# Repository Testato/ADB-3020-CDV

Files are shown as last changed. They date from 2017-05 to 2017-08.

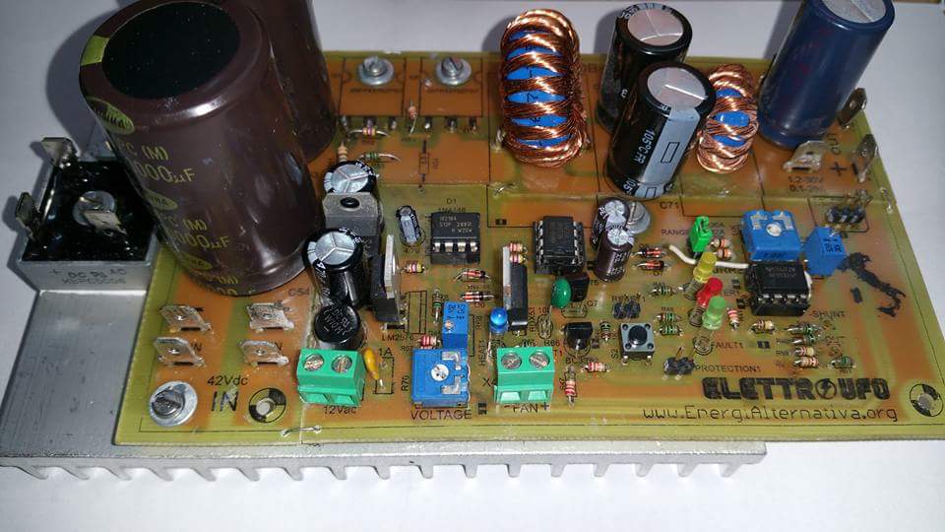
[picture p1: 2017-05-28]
adb_2030_Original/PCB_top_side.jpg

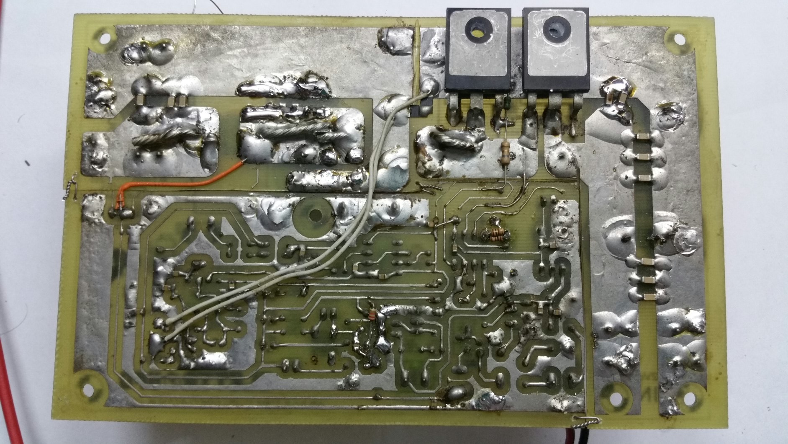
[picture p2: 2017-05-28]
adb_2030_Original/PCB_bottom_side.jpg

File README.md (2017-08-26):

# ADB-3020-CDV



The ADB-3020 is an excellent switching power supply designed by an Italian team and licensed under Creative Commons (the original project and credits are in the adb_2030_Original subfolder).

The CDV (Community Digital Version) fork is intended to start with version 2.1 (last published on the fork date) and then extend it with digital functions via MCU.
The project started with the creation of Eagle .sch because the original authors have decided not to release the productions files. 
Now Eagle file is deprecated, the project is ported on KiCAD.

The CDV version is released under the same license as the original project:
- https://creativecommons.org/licenses/by-nc-sa/4.0/

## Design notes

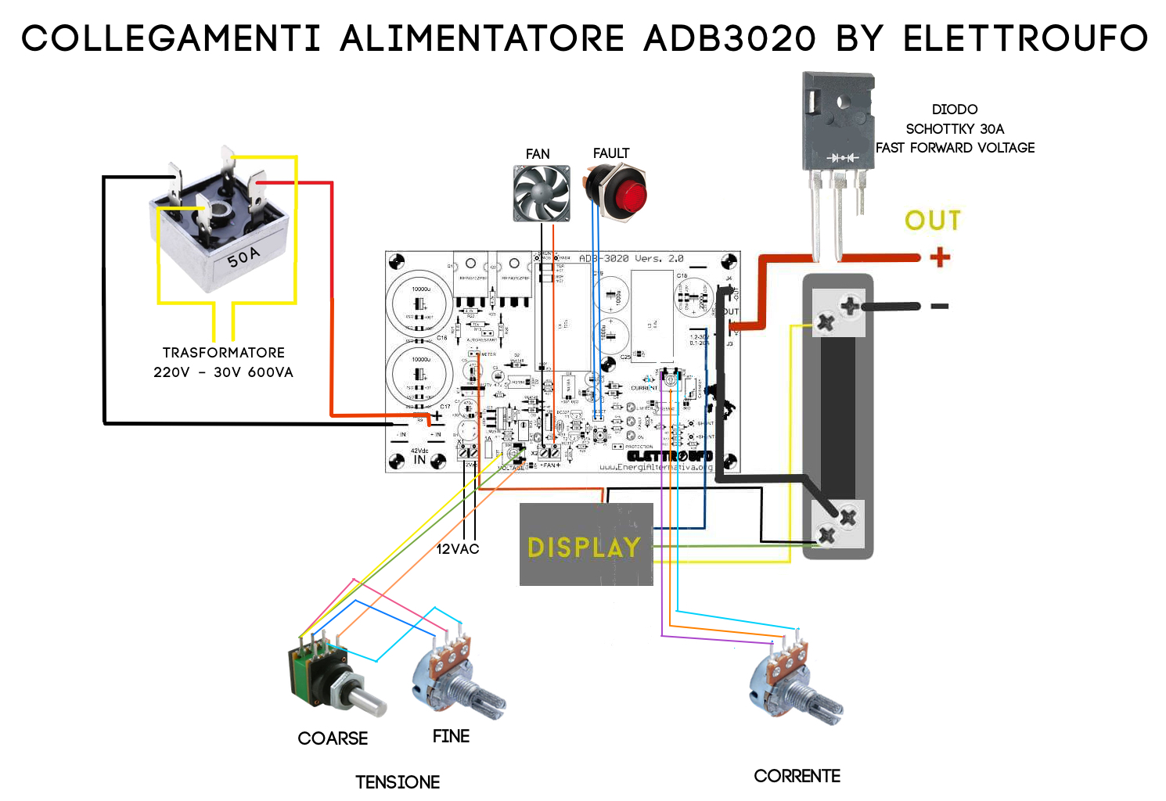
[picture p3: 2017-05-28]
adb_2030_Original/External_connections.jpg

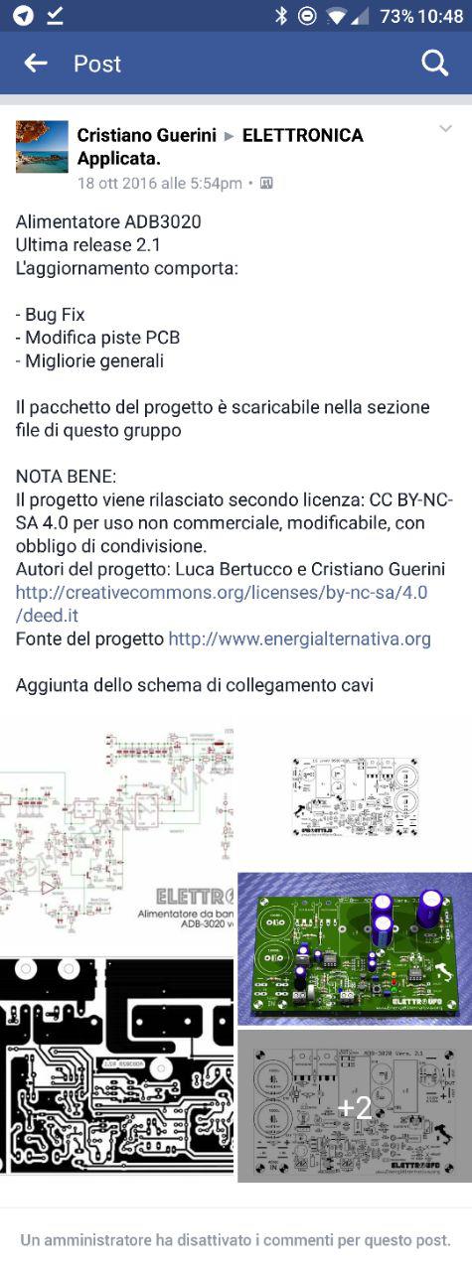
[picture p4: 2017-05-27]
adb_2030_Original/ORIGINAL_LICENCE.jpg

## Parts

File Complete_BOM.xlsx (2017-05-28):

Part | Value | Package | Library | Position (inch) | Orientation | Codice TME | Indirizzo | QTY
B1 | Ponte diodi | RB1A | rectifier | (1.475 0.7625) | R270 | VISHAY 2W01G-E4/51 | http://www.tme.eu/it/details/2w01g-e4_51/ponti-a-diodi-monofase-rotondi/vishay/ | 1
C | 100n | C0805 | rcl | (4.7375 1.2375) | MR270 | SAMSUNG CL21B104KBCNNNC | http://www.tme.eu/it/details/cl21b104kbcnnnc/condensatori-mlcc-smd-0805/samsung/ | 8
C | 100n (100V) | C1206 | rcl | (0.6 1.35) | MR0 | YAGEO CC1206JRX7R9BB104 | http://www.tme.eu/it/details/cc1206kkx7r0104/condensatori-mlcc-smd-1206/yageo/cc1206kkx7r0bb104/ | 5
C | 1000u | E7,5-16 | rcl | (4 3.1625) | R90 | PANASONIC EEUFR1H102 | http://www.tme.eu/it/details/eeufr1h102/condensatori-elettrol-tht-bassa-imped/panasonic/ | 2
C | 10000u | EB30D | rcl | (0.6 3) | R180 | SAMWHA HE1H109M30050HA | http://www.tme.eu/it/details/he1h109m30050ha/condensatori-elettrolitici-snapin-105c/samwha/ | 2
C1 | 470u | E5-8,5 | rcl | (1.475 1.1375) | R180 | SAMXON GT 470U/25V | http://www.tme.eu/it/details/gt470_25/condensatori-elettrol-tht-bassa-imped/samxon/gt-470u25v/ | 2
C11 | 10n | C0805 | rcl | (2.58598954 0.13147047) | MR270 | SAMSUNG CL21B103JBANNNC | http://www.tme.eu/it/details/cl21b103jbannnc/condensatori-mlcc-smd-0805/samsung/ | 3
C15 | 470n | C0805 | rcl | (3.5 0.675) | MR270 | SAMSUNG CL21B474KOFNNNG | http://www.tme.eu/it/details/cl21b474kofnnng/condensatori-mlcc-smd-0805/samsung/ | 1
C18 | 2200u | E7,5-18 | rcl | (5.475 3.1125) | R90 | PANASONIC EEUFC1H222 | http://www.tme.eu/it/details/eeufc1h222/condensatori-elettrol-tht-bassa-imped/panasonic/ | 1
C20 | 10n (100V) | C1206 | rcl | (0.6 2.3375) | MR0 | CL31B103KBCNNNC | http://www.tme.eu/it/details/cl31b103kccnnnc/condensatori-mlcc-smd-1206/samsung/ | 4
C36 | 100u | E2,5-7 | rcl | (3.675 1.6625) | R270 | SR PASSIVES CE-100/35PHT | http://www.tme.eu/it/details/ce-100_35pht/condensatori-elettrolitici-tht-105c/sr-passives/ | 2
C9 | 4.7u | E2,5-6 | rcl | (2 1.7125) | R270 | NICHICON UPW1E4R7MDD | http://www.tme.eu/it/details/upw1e4r7mdd/condensatori-elettrol-tht-bassa-imped/nichicon/ | 1
D1 | 1N4148 | DO35-10 | diode | (2.625 1.2625) | R180 | DIOTEC SEMICONDUCTOR 1N4148 | http://www.tme.eu/it/details/1n4148-dio/diodi-universali-tht/diotec-semiconductor/1n4148/ | 6
D6 | 7812TV | TO220V | linear | (1.55 1.525) | R0 | ST MICROELECTRONICS L7812ABV | http://www.tme.eu/it/details/l7812abv/stabilizzatori-di-tens-non-regolabili/st-microelectronics/ | 1
F1 | PTCPTH | PTC | SparkFun-PowerIC | (1.83053223 0.41229921 | ) R90 | ECE BX075 | http://www.tme.eu/it/details/bx075/fusibili-polimerici-tht/ece/ | 1
IC2 | NE5532 | DIL08 | linear | (5.0125 1.1375) | R0 | TEXAS INSTRUMENTS NE5532P | http://www.tme.eu/it/details/ne5532p/amplificatori-operazionali-tht/texas-instruments/ | 1
IC3 | LM2576 | TO220-51 | linear | (2.1375 0.9625) | R270 | TEXAS INSTRUMENTS LM2576HVT-ADJ/LF03 | http://www.tme.eu/it/details/lm2576hvtadj_lf/regolatori-di-tensione-circuiti-dc-dc/texas-instruments/lm2576hvt-adjlf03/ | 1
IC4 | NE555 | DIL-08 | st-microelectronics | (3.25 1.525) | R90 | TEXAS INSTRUMENTS NE555P | http://www.tme.eu/it/details/ne555p/circuiti-watchdog-e-reset/texas-instruments/ | 1
IC5 | IR2184D | DIL08 | irs | (2.375 1.6125) | R0 | INFINEON (IRF) IR2184PBF | http://www.tme.eu/it/details/ir2184pbf/driver-mosfetigbt/infineon-irf/ | 1
Jumper |  | JP1 | jumper | (1.575 2.1125) | R90 | NINIGI JUMPER-H/B | http://www.tme.eu/it/details/jumper-h_b/prese-e-spine-tipo-c-gird/ninigi/ | 3
L3 | 6.8u | TJ7-U1 | resistor | (4.7375 2.775) | R0 | FERYSTER DTMSS-16/0.0068/20-V | http://www.tme.eu/it/details/dtmss-16_0.0068_20/induttori-ad-anello/feryster/dtmss-160006820-v/ | 1
L4 | 100u | TJ8-U1 | resistor | (3.15 2.7625) | R0 | FERYSTER DTMSS-47/0.10/30-V | http://www.tme.eu/it/details/dtmss-47_0.10_30-v/induttori-ad-anello/feryster/ | 1
Lastra rame | 100x160 |  |  |  |  | LAM100X160L1.5 | http://www.tme.eu/it/details/lam100x160l1.5/laminati-unilaterali/ | 1
led FAULT | Red | LED3MM | led | (4.35 0.9125) | R180 | KINGBRIGHT ELECTRONIC L-934SRD-F | http://www.tme.eu/it/details/l-934srd-f/diodi-led-tht-3mm/kingbright-electronic/ | 1
led HEAT | Green | LED3MM | led | (2.7 0.625) | R180 | KINGBRIGHT ELECTRONIC L-934GD | http://www.tme.eu/it/details/l-934gd/diodi-led-tht-3mm/kingbright-electronic/ | 1
led LIMITER | Yellow | LED3MM | led | (4.35 1.1625) | R180 | OPTOSUPPLY OSNY3134B | http://www.tme.eu/it/details/osny3134b/diodi-led-tht-3mm/optosupply/ | 1
led ON | blue | LED3MM | led | (4.35 0.6625) | R180 | OPTOSUPPLY OSC34L3131A | http://www.tme.eu/it/details/osc34l3131a/diodi-led-tht-3mm/optosupply/ | 1
Pomello |  | 6,35mm liscio |  |  |  | SR PASSIVES G33-S | http://www.tme.eu/it/details/g33-s/manopole-per-potenziometri-assiali/sr-passives/ | 1
Pomello |  | 6mm zigri |  |  |  | SR PASSIVES GW28B | http://www.tme.eu/it/details/gw28b/manopole-per-potenziometri-assiali/sr-passives/ | 2
Pot. Tensione | 50K doppio | dia 6 zigri |  |  |  | PIHER PC16DH10IP06503A2020TA | http://www.tme.eu/it/details/6psi-50k/potenziometri-a-carbone-mono-giro/piher/pc16dh10ip06503a2020ta/ | 1
Pot. Tensione | 10K multigiri | dia 6,35 liscio |  |  |  | SR PASSIVES POT2218P-10K | http://www.tme.eu/it/details/pot2218p-10k/potenziometri-a-filo-multi-giri/sr-passives/ | 1
Pot. Corrente | 10K | dia 6 zigri |  |  |  | SR PASSIVES R16148-1A-2-B10K | http://www.tme.eu/it/details/r16148-1a-2-b10k/potenziometri-a-carbone-mono-giro/sr-passives/ | 1
Q1 | IRFP4310ZPBF | TO247BH | transistor-power | (1.5125 3.3625) | R0 | INFINEON (IRF) IRFP4310ZPBF | http://www.tme.eu/it/details/irfp4310zpbf/transistori-con-canale-n-tht/infineon-irf/ | 2
Q4 | BDX53 | TO126AV | transistor-power | (2.95 0.9) | R270 | ON SEMICONDUCTOR BDX53CG | http://www.tme.eu/it/details/bdx53cg/transistori-di-darlington-npn-tht/on-semiconductor/ | 1
R | 100 | 0204/5 | resistor | (5.175 0.5125) | R180 | ROYAL OHM CFR0S4J0101A50 | http://www.tme.eu/it/details/1_4ws100r/resistori-a-carbone-subminiat-tht-14w/royal-ohm/cfr0s4j0101a50/ | 1
R | 560 | 0204/5 | resistor | (2.725 0.8875) | R90 | ROYAL OHM CFR0S4J0561A50 | http://www.tme.eu/it/details/1_4ws560r/resistori-a-carbone-subminiat-tht-14w/royal-ohm/cfr0s4j0561a50/ | 1
R | 30k | 0204/5 | resistor | (5.175 0.6125) | R0 | ROYAL OHM CFR0S4J0303A50 | http://www.tme.eu/it/details/1_4ws30k/resistori-a-carbone-subminiat-tht-14w/royal-ohm/cfr0s4j0303a50/ | 2
R | 4.7K | 0204/5 | resistor | (2.17164124 0.60468873 | ) R0 | ROYAL OHM CFR0S4J0472A50 | http://www.tme.eu/it/details/1_4ws4k7/resistori-a-carbone-subminiat-tht-14w/royal-ohm/cfr0s4j0472a50/ | 5
R | 220 | 0207/12 | resistor | (1.225 2.525) | R270 | ROYAL OHM CFR0S4J0221A50 | http://www.tme.eu/it/details/1_4ws220r/resistori-a-carbone-subminiat-tht-14w/royal-ohm/cfr0s4j0221a50/ | 1
R1 | 22k | 0204/5 | resistor | (3.3875 0.8875) | R0 | ROYAL OHM CFR0S4J0223A50 | http://www.tme.eu/it/details/1_4ws22k/resistori-a-carbone-subminiat-tht-14w/royal-ohm/cfr0s4j0223a50/ | 5
R | 1k | 0204/5 | resistor | (4.1125 1.1625) | R0 | ROYAL OHM CFR0S4J0102A50 | http://www.tme.eu/it/details/1_4ws1k/resistori-a-carbone-subminiat-tht-14w/royal-ohm/cfr0s4j0102a50/ | 9
R | 10k | 0207/10 | resistor | (1.7 2.525) | R0 | ROYAL OHM CFR0S4J0103A50 | http://www.tme.eu/it/details/1_4ws10k/resistori-a-carbone-subminiat-tht-14w/royal-ohm/cfr0s4j0103a50/ | 3
R 1W | 10k | 0207/10 | resistor | (0.625 1.025) | R0 | SR PASSIVES CF1WS-10K | http://www.tme.eu/it/details/cf1ws-10k/resistori-a-strato-di-carbone-tht-1w/sr-passives/ | 2
R14 | 2.2K | 0204/5 | resistor | (2.175 0.7) | R180 | ROYAL OHM CFR0S4J0222A50 | http://www.tme.eu/it/details/1_4ws2k2/resistori-a-carbone-subminiat-tht-14w/royal-ohm/cfr0s4j0222a50/ | 1
R18 | 1M | 0204/5 | resistor | (3.3875 0.8) | R180 | ROYAL OHM CFR0S4J0105A50 | http://www.tme.eu/it/details/1_4ws1m/resistori-a-carbone-subminiat-tht-14w/royal-ohm/cfr0s4j0105a50/ | 1
R19 | 1k | RTRIM3296Y | rcl | (5.4125 1.4875) | R0 | BOURNS 3296Y-1-102LF | http://www.tme.eu/it/details/3296y-1-102lf/potenziometri-tht-multi-giri-38-pollice/bourns/ | 1
R24 | 6.8 | 0207/15 | resistor | (2.05 2.525) | R270 | ROYAL OHM CFR0S4J068JA50 | http://www.tme.eu/it/details/1_4ws6r8/resistori-a-carbone-subminiat-tht-14w/royal-ohm/cfr0s4j068ja50/ | 1
R25 | 15k | 0204/5 | resistor | (4.6875 1.65) | R0 | ROYAL OHM CFR0S4J0153A50 | http://www.tme.eu/it/details/1_4ws15k/resistori-a-carbone-subminiat-tht-14w/royal-ohm/cfr0s4j0153a50/ | 1
R26 | 10m | R2512 | rcl | (2.8625 3.45) | MR180 | VIKING LRP12FTWRR010 | http://www.tme.eu/it/details/lrp2512-r010-1%25/resistori-smd-2512/viking/lrp12ftwrr010/ | 2
R33 | 10k | P642 | ptc-ntc | (3.1 0.825) | R270 | SR PASSIVES NTCC-10K | http://www.tme.eu/it/details/ntcc-10k/termistori-ntc-di-rilievo-tht/sr-passives/ | 1
R35 | 1k | RTRIM3296Y | rcl | (2.45 0.75) | R180 | BOURNS 3296Y-1-102LF | http://www.tme.eu/it/details/3296y-1-102lf/potenziometri-tht-multi-giri-38-pollice/bourns/ | 1
R40 1w | 1k | 0309/12 | resistor | (5.925 2.925) | R270 | ROYAL OHM MOR01SJ0102A10 | http://www.tme.eu/it/details/1w-1k/resistori-a-strato-metallico-tht-1w/royal-ohm/mor01sj0102a10/ | 1
Radiatore |  |  |  |  |  | STONECOLD RAD-P3698/100 | http://www.tme.eu/it/details/rad-p3698_100/radiatori/stonecold/ | 1
S1 |  | B3F-10XX | switch-omron | (3.8125 0.6625) | R90 | NINIGI TACT-64N-F | http://www.tme.eu/it/details/tact-64n-f/microinterruttori-tact-pcb/ninigi/ | 1
Strip Maschio | Jumper |  | con-faston | (0.9 0.85) | R180 | CONNFLY DS1021-1*16SF11 | http://www.tme.eu/it/details/zl201-16g/prese-e-spine-tipo-c-gird/connfly/ds1021-1_16sf11/ | 1
T1 | BC337 | TO92 | transistor | (3.3875 1.05) | R180 | DIOTEC SEMICONDUCTOR BC337-16BK | http://www.tme.eu/it/details/bc337-16bk-dio/transistori-npn-tht/diotec-semiconductor/bc337-16bk/ | 2
X1, X2 |  | AK500/2 | con-ptr500 | (1.475 0.35) | R0 | ADAM TECH EB21A-02-D | http://www.tme.eu/it/details/eb21a-02-d/morsettiere-per-circuiti-stampati/adam-tech/ | 2
Isol. Termocond. | Silicone | TO247 |  |  |  | FISCHER ELEKTRONIK WK 247 | http://www.tme.eu/it/details/wk_247/radiatori-equipaggiamento/fischer-elektronik/wk-247/ | 2
Trasformatore 1 | 2x30V – 2x10A |  |  |  |  | INDEL TST600/006 | http://www.tme.eu/it/details/tst600w_2x17v/trasformatori-toroidali/indel/tst600006/ | 1
Trasformatore 2 | 12V – 1A |  |  |  |  |  | http://www.tme.eu/it/details/tszzbd12_001m/trasformatori-con-fissaggio/indel/tszzbd-12001m/ | 1
Ponte Diodi | 50A |  |  |  |  | DC COMPONENTS KBPC5010 | http://www.tme.eu/it/details/kbpc5010f/ponti-a-diodi-monofase-quadrati/dc-components/kbpc5010/ | 1
Diodo Schottky | 30A |  |  |  |  | VISHAY MBR3060PT-E3/45 | http://www.tme.eu/it/details/mbr3060pt-e3_45/diodi-schottky-tht/vishay/ | 1
Display A-V | Meter + ext. Shunt |  |  |  |  |  | https://aliexpress.com/item/Dual-LED-Digital-Voltmeter-Ammeter-Amp-Volt-Meter-Current-Shunt-DC-100V-50A-U225/32795476928.html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 | 1
Conn x faston M |  |  |  |  |  | OSTERRATH 61-1536-11/0031 | http://www.tme.eu/it/details/fs1536_nc/terminali-a-saldare-pcb/osterrath/61-1536-110031/ | 10
Conn x faston F |  |  |  |  |  |  | http://www.tme.eu/it/details/3-520408-2/connettori-isolati/te-connectivity/ | 10

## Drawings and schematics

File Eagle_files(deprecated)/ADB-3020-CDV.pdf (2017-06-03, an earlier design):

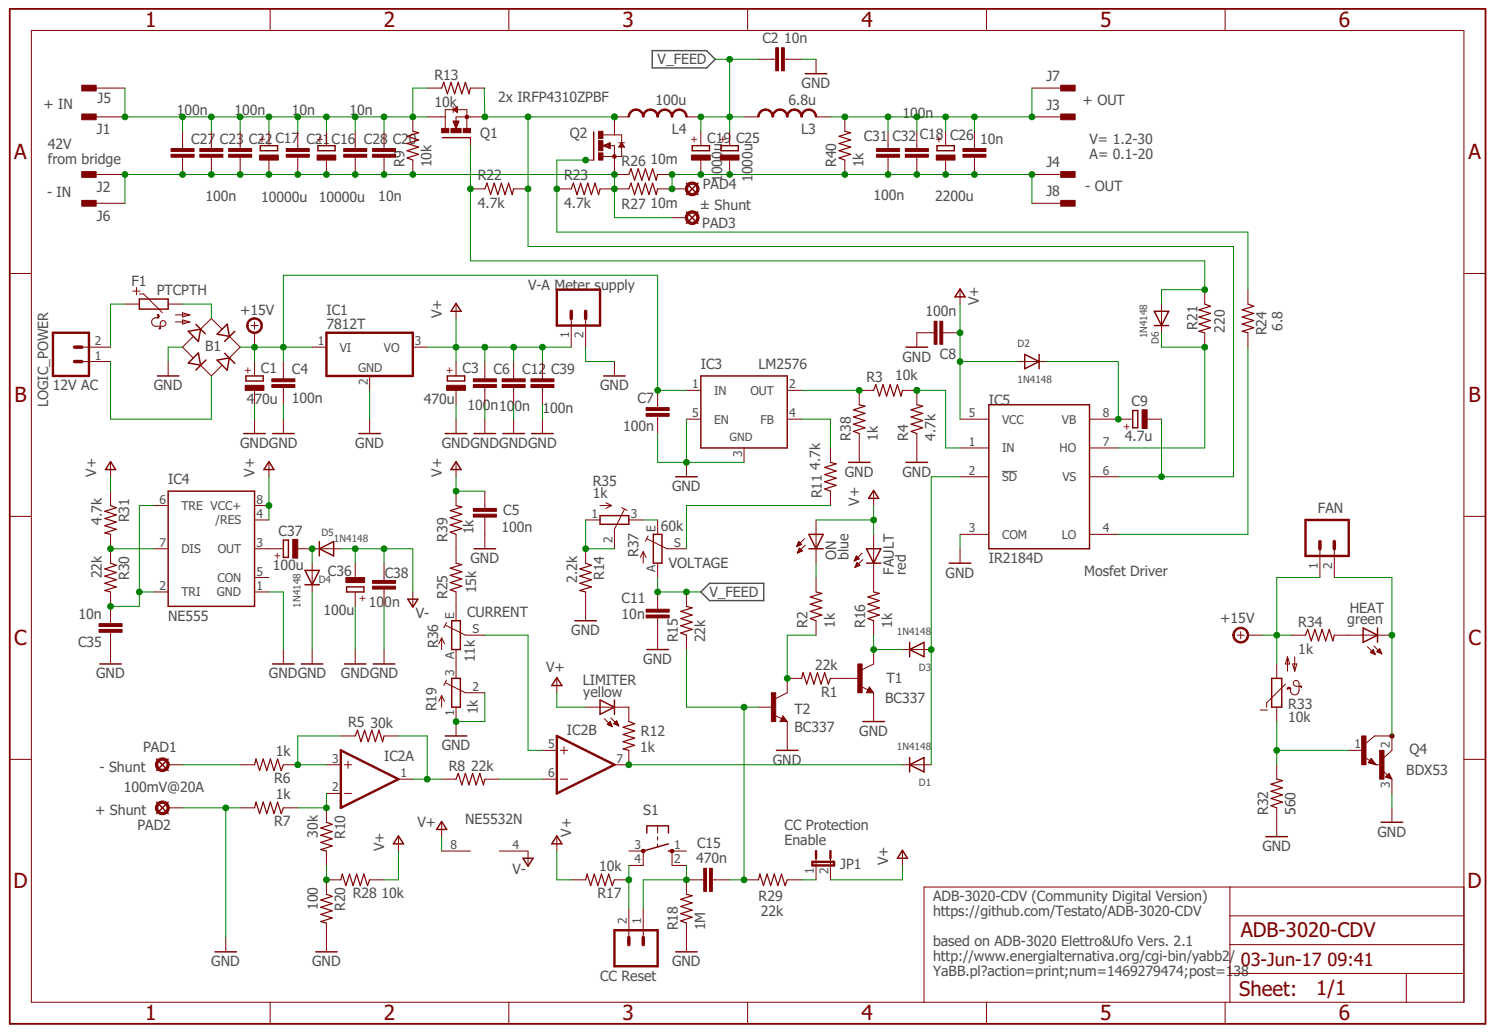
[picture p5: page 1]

ADB-3020-CDV (Community Digital Version) https://github.com/Testato/ADB-3020-CDV based on ADB-3020 Elettro&Ufo Vers. 2.1 http://www.energialternativa.org/cgi-bin/yabb2/

YaBB.pl?action=print;num=1469279474;post=138

Sheet: 1/1

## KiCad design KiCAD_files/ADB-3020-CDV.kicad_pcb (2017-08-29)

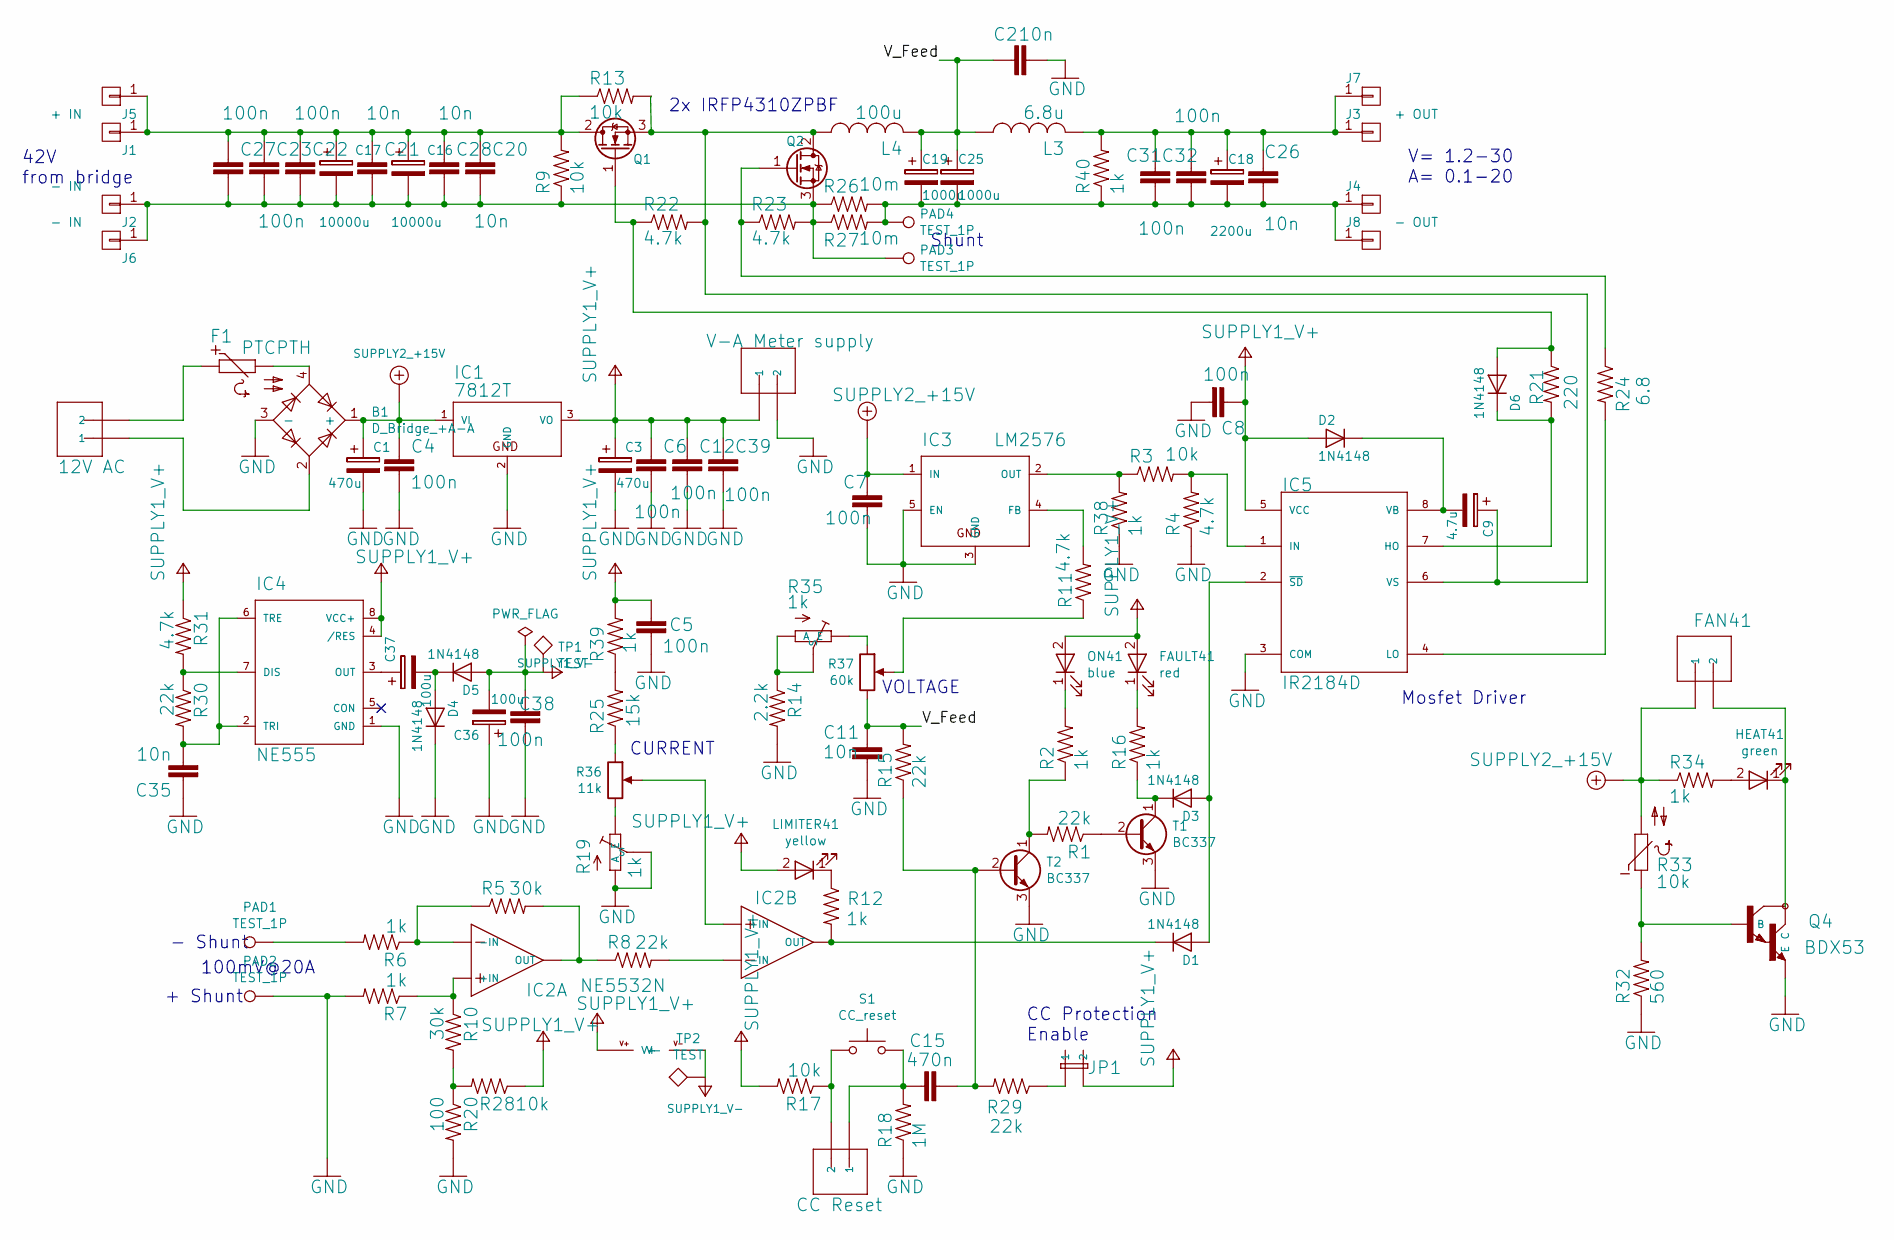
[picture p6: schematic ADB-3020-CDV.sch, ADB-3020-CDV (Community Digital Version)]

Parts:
B1: D_Bridge_+A-A; Diode_Bridge_Round_D9.8mm
C1, C3: 470u; CP_Radial_D10.0mm_P5.00mm
C2, C11, C35: 10n; C_0805
C4, C5, C6, C7, C8, C12, C38, C39: 100n; C_0805
C9: 4.7u; CP_Radial_D5.0mm_P2.00mm
C15: 470n; C_0805
C16, C17: 10000u; CP_Radial_D30.0mm_P10.00mm_SnapIn
C18: 2200u; CP_Radial_D18.0mm_P7.50mm
C19, C25: 1000u; CP_Radial_D16.0mm_P7.50mm
C20, C21, C26, C28: 10n; C_1206
C22, C23, C27, C31, C32: 100n; C_1206
C36, C37: 100u; CP_Radial_D6.3mm_P2.50mm
D1, D2, D3: 1N4148; D_DO-35_SOD27_P10.16mm_Horizontal
D4, D5: 1N4148; D_DO-35_SOD27_P7.62mm_Horizontal
D6: 1N4148; D_DO-35_SOD27_P12.70mm_Horizontal
F1: PTCPTH; R_Axial_DIN0204_L3.6mm_D1.6mm_P5.08mm_Horizontal
FAN41: fan; PhoenixContact_MCV-G_02x5.08mm_Vertical
FAULT41: red; LED_D3.0mm
HEAT41: green; LED_D3.0mm
IC1: 7812T; TO-220_Vertical
IC2: NE5532N; DIP-8_W7.62mm_LongPads
IC3: LM2576; TO-220-5_Pentawatt_Multiwatt-5_Vertical_StaggeredType1
IC4: NE555; DIP-8_W7.62mm_LongPads
IC5: IR2184D; DIP-8_W7.62mm_LongPads
J1, J5: + IN; faston_6.3mm
J2, J6: - IN; faston_6.3mm
J3, J7: + OUT; faston_6.3mm
J4, J8: - OUT; faston_6.3mm
JP1: jp1; Pin_Header_Straight_1x02_Pitch2.54mm
L3: 6.8u; smallinductor
L4: 100u; biginductor
LIMITER41: yellow; LED_D3.0mm
LOGIC_POWER41: 12V AC; PhoenixContact_MCV-G_02x5.08mm_Vertical
ON41: blue; LED_D3.0mm
PAD1, PAD2, PAD3, PAD4: TEST_1P; SolderWirePad_single_1mmDrill
Q1, Q2: IRFP4310ZPBF; TO-247_TO-3P_Horizontal
Q4: BDX53; TO-126_Vertical
R1, R8, R29, R30: 22k; R_Axial_DIN0204_L3.6mm_D1.6mm_P5.08mm_Horizontal
R2, R7, R12, R16, R34, R39: 1k; R_Axial_DIN0204_L3.6mm_D1.6mm_P5.08mm_Horizontal
R3: 10k; R_Axial_DIN0204_L3.6mm_D1.6mm_P7.62mm_Horizontal
R4, R11, R31: 4.7k; R_Axial_DIN0204_L3.6mm_D1.6mm_P5.08mm_Horizontal
R5, R10: 30k; R_Axial_DIN0204_L3.6mm_D1.6mm_P5.08mm_Horizontal
R6: 1k; R_Axial_DIN0204_L3.6mm_D1.6mm_P7.62mm_Horizontal
R9, R13: 10k; R_Axial_DIN0207_L6.3mm_D2.5mm_P10.16mm_Horizontal
R14: 2.2k; R_Axial_DIN0204_L3.6mm_D1.6mm_P5.08mm_Horizontal
R15: 22k; R_Axial_DIN0204_L3.6mm_D1.6mm_P7.62mm_Horizontal
R17, R28: 10k; R_Axial_DIN0204_L3.6mm_D1.6mm_P5.08mm_Horizontal
R18: 1M; R_Axial_DIN0204_L3.6mm_D1.6mm_P5.08mm_Horizontal
R19, R35: 1k; Potentiometer_Trimmer_Bourns_3296Y
R20: 100; R_Axial_DIN0204_L3.6mm_D1.6mm_P5.08mm_Horizontal
R21: 220; R_Axial_DIN0207_L6.3mm_D2.5mm_P15.24mm_Horizontal
R22, R23: 4.7k; R_Axial_DIN0207_L6.3mm_D2.5mm_P10.16mm_Horizontal
R24: 6.8; R_Axial_DIN0207_L6.3mm_D2.5mm_P15.24mm_Horizontal
R25: 15k; R_Axial_DIN0204_L3.6mm_D1.6mm_P5.08mm_Horizontal
R26, R27: 10m; R_2512
R32: 560; R_Axial_DIN0204_L3.6mm_D1.6mm_P5.08mm_Horizontal
R33: 10k; R_Axial_DIN0204_L3.6mm_D1.6mm_P2.54mm_Vertical
R36: 11k; Potentiometer_Trimmer_ACP_CA9v_Horizontal_Px10.0mm_Py5.0mm
R37: 60k; Potentiometer_Trimmer_ACP_CA9v_Horizontal_Px10.0mm_Py5.0mm
R38: 1k; R_Axial_DIN0207_L6.3mm_D2.5mm_P10.16mm_Horizontal
R40: 1k; R_Axial_DIN0309_L9.0mm_D3.2mm_P12.70mm_Horizontal
RESET41: CC Reset; Pin_Header_Straight_1x02_Pitch2.54mm
S1: CC_reset; SW_PUSH_6mm
T1, T2: BC337; TO-92_Molded_Narrow
TP1, TP2: TEST; SolderWirePad_single_1mmDrill
V-A_METER_SUPPLY41: V-A Meter supply; Pin_Header_Straight_1x02_Pitch2.54mm

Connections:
+15V: B1.1 (+), C1.1, C4.1, C7.1, FAN41.1, IC1.1 (VI), IC3.1 (IN), R33.2, R34.1
/V_Feed: C2.1, C11.1, C19.1, C25.1, L3.1, L4.2, R15.2, R37.3
GND: B1.3 (-), C1.2, C2.2, C3.2, C4.2, C5.1, C6.2, C7.2, C8.2, C11.2, C12.2, C35.1, C36.1, C38.1, C39.2, D4.1 (K), IC1.2 (GND), IC3.3 (GND), IC3.5 (EN), IC4.1 (GND), IC5.3 (COM), PAD2.1, Q4.3 (E), R4.1, R7.2, R14.2, R18.1, R19.1 (A), R19.2 (S), R20.2, R32.1, R38.1, T1.3 (E), T2.3 (E), V-A_METER_SUPPLY41.2
unnamed: B1.2, LOGIC_POWER41.1
unnamed: B1.4, F1.2
unnamed: C9.1, IC5.6 (VS), L4.1, Q1.3 (S), Q2.2 (D), R13.2, R22.2
unnamed: C9.2, D2.1 (K), IC5.8 (VB)
unnamed: C15.1, R18.2, RESET41.1, S1.2
unnamed: C15.2, R15.1, R29.2, T2.2 (B)
unnamed: C16.1, C17.1, C20.1, C21.1, C22.1, C23.1, C27.1, C28.1, J1.1, J5.1, Q1.2 (D), R9.2, R13.1
unnamed: C16.2, C17.2, C20.2, C21.2, C22.2, C23.2, C27.2, C28.2, J2.1, J6.1, PAD3.1, Q2.3 (S), R9.1, R23.2, R26.1, R27.1
unnamed: C18.1, C26.1, C31.1, C32.1, J3.1, J7.1, L3.2, R40.2
unnamed: C18.2, C19.2, C25.2, C26.2, C31.2, C32.2, J4.1, J8.1, PAD4.1, R26.2, R27.2, R40.1
unnamed: C35.2, IC4.2 (TRI), IC4.6 (TRE), R30.2
unnamed: C37.1, IC4.3 (OUT)
unnamed: C37.2, D4.2 (A), D5.1 (K)
unnamed: D1.1 (K), IC2.7 (OUT), R12.2
unnamed: D1.2 (A), D3.2 (A), IC5.2 (~SD)
unnamed: D3.1 (K), R16.1, T1.1 (C)
unnamed: D6.1 (K), IC5.7 (HO), R21.2
unnamed: D6.2 (A), Q1.1 (G), R21.1, R22.1
unnamed: F1.1, LOGIC_POWER41.2
unnamed: FAN41.2, HEAT41.1 (K), Q4.2 (C)
unnamed: FAULT41.1 (K), R16.2
unnamed: HEAT41.2 (A), R34.2
unnamed: IC2.1 (OUT), R5.2, R8.1
unnamed: IC2.2 (-IN), R5.1, R6.1
unnamed: IC2.3 (+IN), R7.1, R10.1
unnamed: IC2.5 (+IN), R36.2
unnamed: IC2.6 (-IN), R8.2
unnamed: IC3.2 (OUT), R3.1, R38.2
unnamed: IC3.4 (FB), R11.2
unnamed: IC4.7 (DIS), R30.1, R31.2
unnamed: IC5.1 (IN), R3.2, R4.2
unnamed: IC5.4 (LO), R24.2
unnamed: JP1.1, R29.1
unnamed: LIMITER41.1 (K), R12.1
unnamed: ON41.1 (K), R2.2
unnamed: PAD1.1, R6.2
unnamed: Q2.1 (G), R23.1, R24.1
unnamed: Q4.1 (B), R32.2, R33.1
unnamed: R1.1, T1.2 (B)
unnamed: R1.2, R2.1, T2.1 (C)
unnamed: R10.2, R20.1, R28.2
unnamed: R11.1, R37.2
unnamed: R14.1, R35.1 (A), R35.2 (S)
unnamed: R17.1, RESET41.2, S1.1
unnamed: R19.3 (E), R36.3
unnamed: R25.1, R36.1
unnamed: R25.2, R39.1
unnamed: R35.3 (E), R37.1
V+: C3.1, C5.2, C6.1, C8.1, C12.1, C39.1, D2.2 (A), FAULT41.2 (A), IC1.3 (VO), IC2.8 (V+), IC4.4 (/RES), IC4.8 (VCC+), IC5.5 (VCC), JP1.2, LIMITER41.2 (A), ON41.2 (A), R17.2, R28.1, R31.1, R39.2, V-A_METER_SUPPLY41.1
V-: C36.2, C38.2, D5.2 (A), IC2.4 (V-), TP1.1, TP2.1

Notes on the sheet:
2x IRFP4310ZPBF
100mV@20A
- Shunt
+ Shunt
~ Shunt
42V from bridge
V= 1.2-30 A= 0.1-20
CURRENT
VOLTAGE
CC Protection Enable
Mosfet Driver

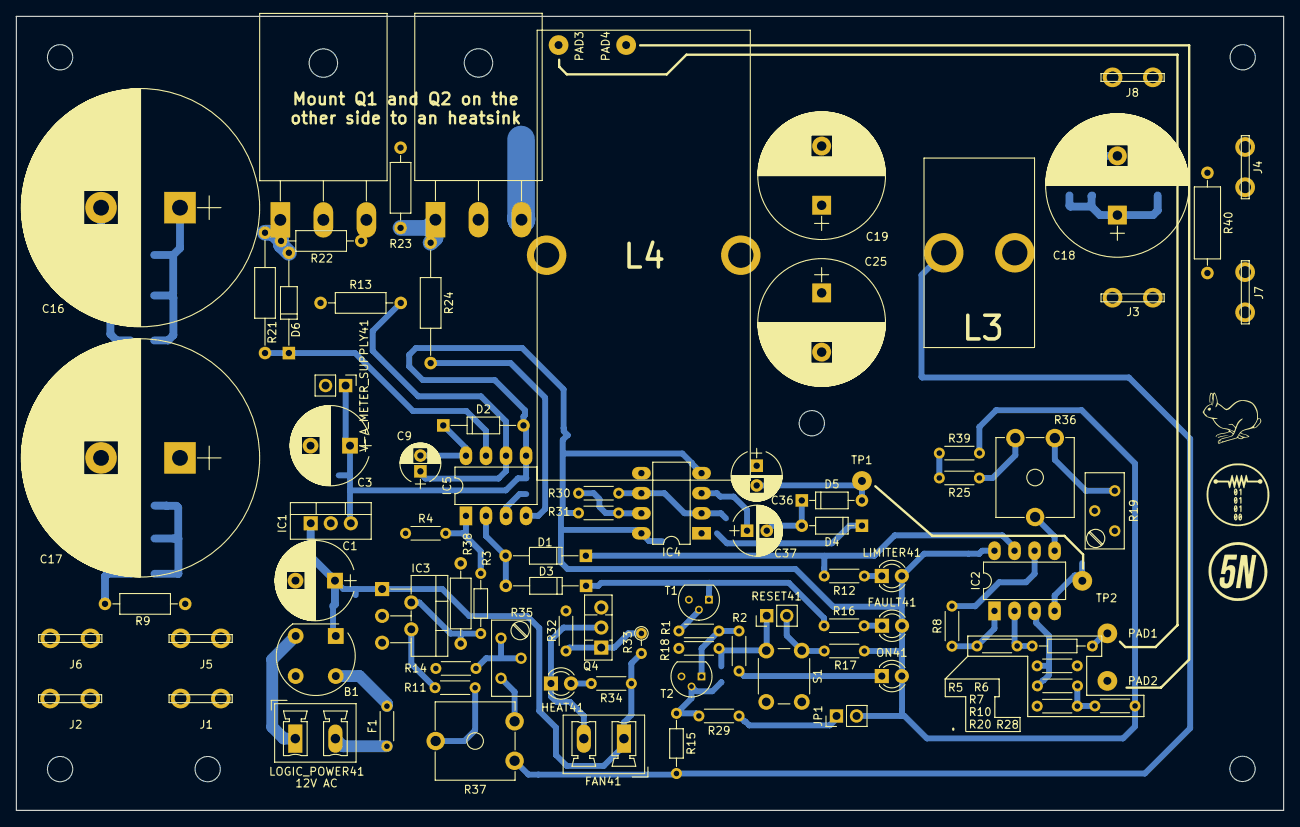
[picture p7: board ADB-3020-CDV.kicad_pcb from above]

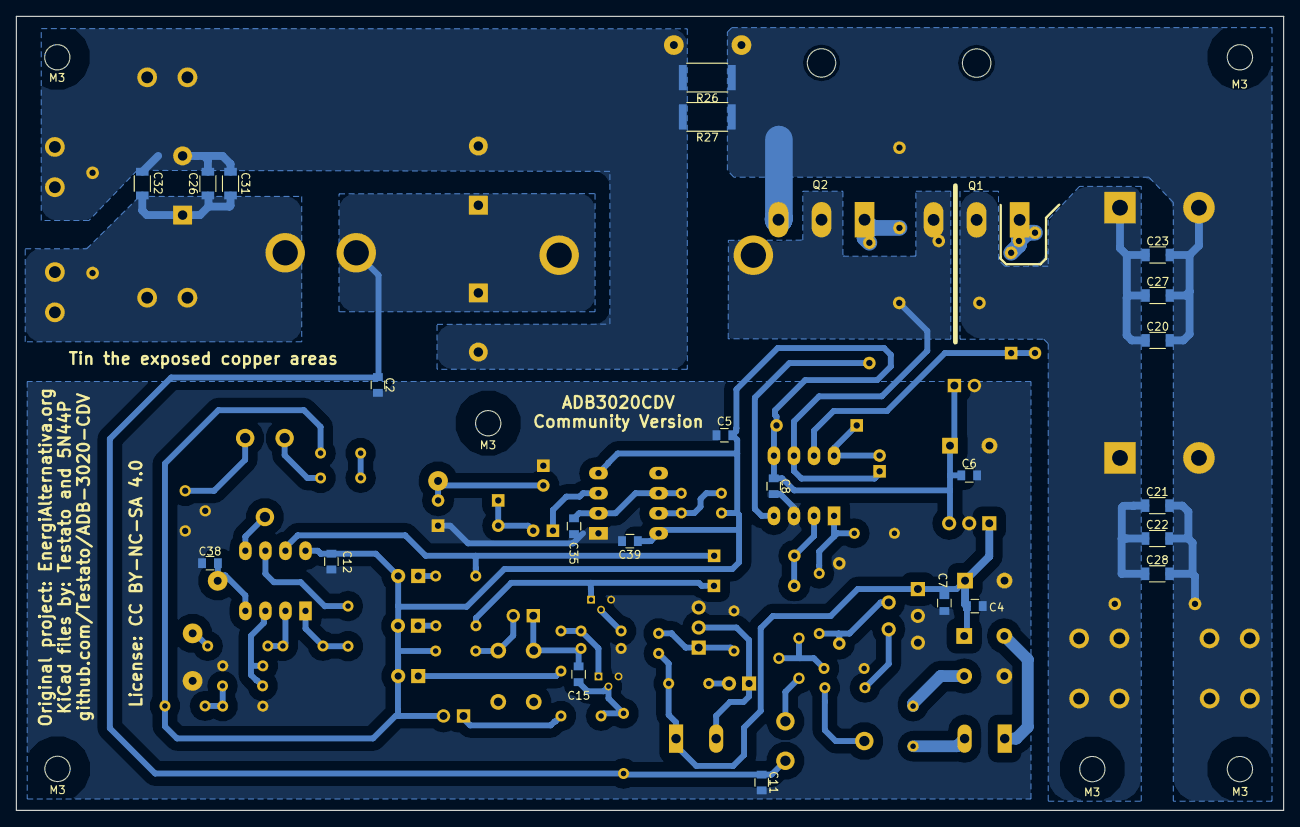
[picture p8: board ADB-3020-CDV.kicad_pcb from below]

Board: 2 copper layers, 160.5 x 100.6 mm, 121 parts (29 on the bottom side), 53 nets.

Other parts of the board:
M3, M3#2, M3#3, M3#4, M3#5, M3#6: MountingHole_3.2mm_M3

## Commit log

2017-05-27 added ne5532 supply pins
    [ADB-3020-CDV.sch]
2017-05-28 Complete boom included external components
    [Complete_BOM.xlsx]
2017-05-28 info added
    [ADB-3020-CDV.sch]
2017-05-30 Added components values, reviewed some connections
    Waiting for a review before merge
    [ADB-3020-CDV.sch]
2017-05-31 Fixed component designators
    Fixed components designators to match those in the original schematic and bom
    [ADB-3020-CDV.sch]
2017-05-31 Fixed some connections
    [ADB-3020-CDV.sch]
2017-06-02 Grid 0,1" + some component name corrections
    [ADB-3020-CDV.sch]
2017-06-03 removed unused joint connection + minor graphic change
    [ADB-3020-CDV.sch]
2017-08-26 first KiCAD version whit sch and pcb
    [ADB-3020-CDV.brd, ADB-3020-CDV.kicad_pcb, ADB-3020-CDV.sch]
2017-08-29 Completed the layout
    [ADB-3020-CDV.kicad_pcb, ADB-3020-CDV.sch, zones_dump.txt]
2017-08-30 Removed all ERC, repaired annotation on sch and pcb, added sheet pcb info, revisited .sch component name value position
    [ADB-3020-CDV.sch]

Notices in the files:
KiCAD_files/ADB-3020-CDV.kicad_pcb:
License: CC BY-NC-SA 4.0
